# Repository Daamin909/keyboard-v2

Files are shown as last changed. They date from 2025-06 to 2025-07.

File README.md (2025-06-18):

# keyboard - v2

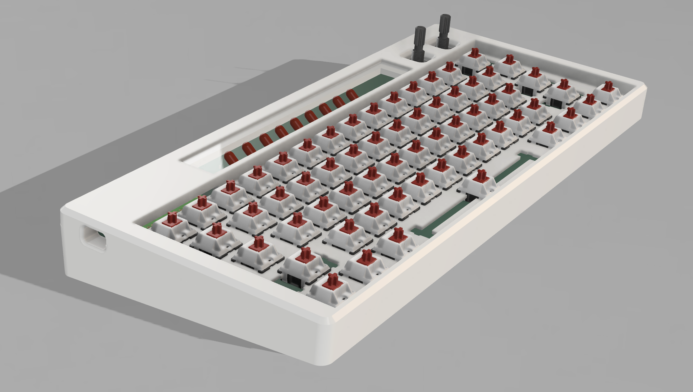
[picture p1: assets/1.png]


Made by [Daamin](https://daamin.tech)

Features:

- 61x keys!
- Default 60% Layout
- 2x EC11 Rotary Encoder - For Volume, Brightness etc
- 9x LEDs with acrylic for aesthetics (multicolor)
- COOOL Silkscreen
- 5° inclined case
- Comfy Design
- KMK firmware

## Info

I made this keyboard since I wanted a compact alternative to my bigger keyboard, this keyboard is pretty small in size and has most of the necessary keys. I also wanted to make this one look aesthetically pleasing instead of my old keyboard which did not look really good 😭.

It has 9x LEDs, out of which 3 are Red, Blue and Green. I did not use neopixels since PCBA is a bit expensive, and SMD soldering is out of my league for now.

In order to mount the acrylic sheet that is on top of the cutout, I designed a 3D printed part that will be super glued to hold it in place.

I will be using a cool green gradient keycaps, which will blend really well with the white case and the black PCB. The PCB will be visible from the LED cutout. The silkscreen also looks very good and is Harry Potter Themed.

## PCB

The PCB's size is 290.9mm x 123.4mm

| Schematic                 |
| ------------------------- |
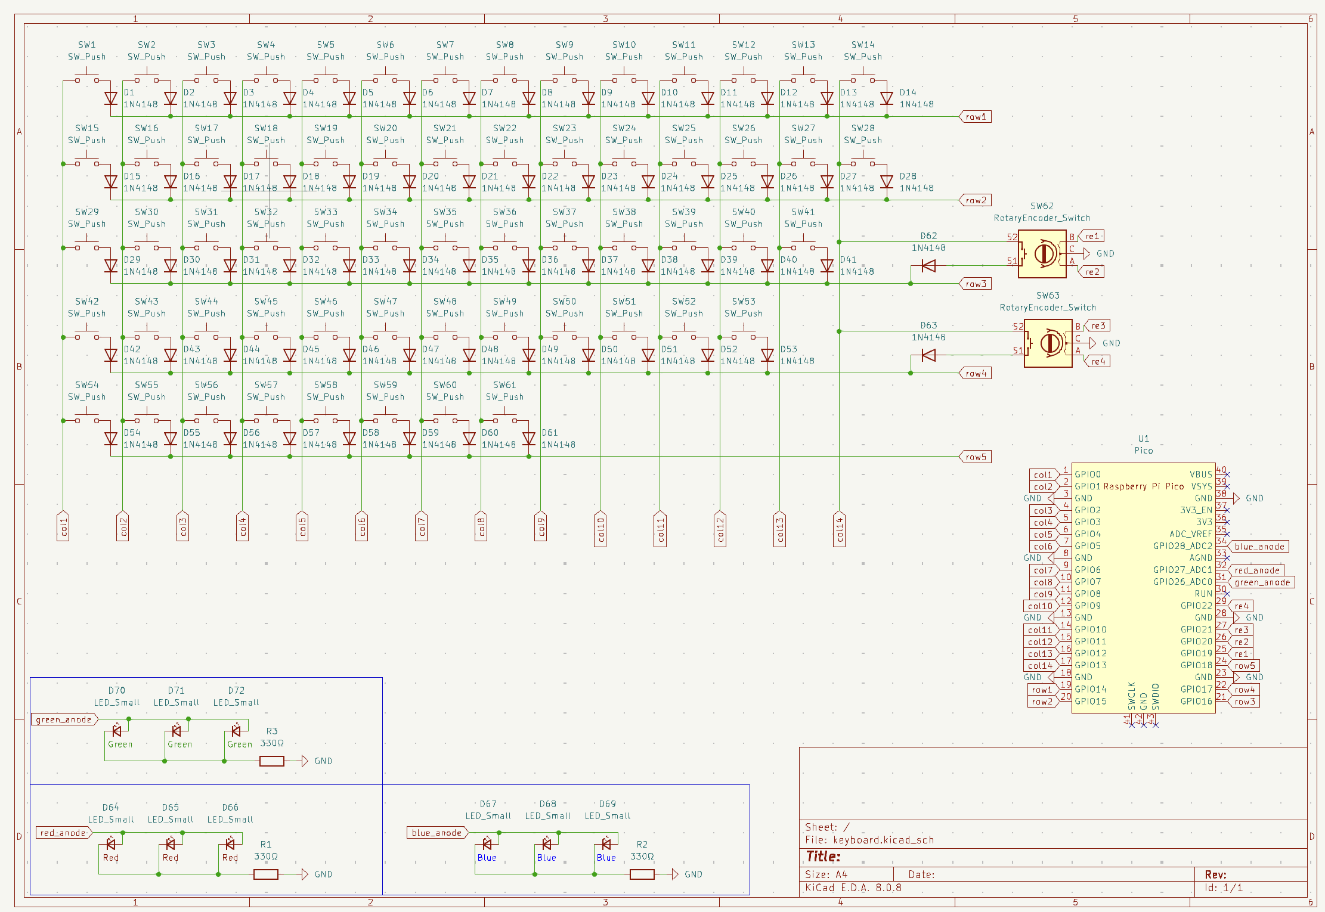
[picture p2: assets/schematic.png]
|  |

| Front                 |
| --------------------- |
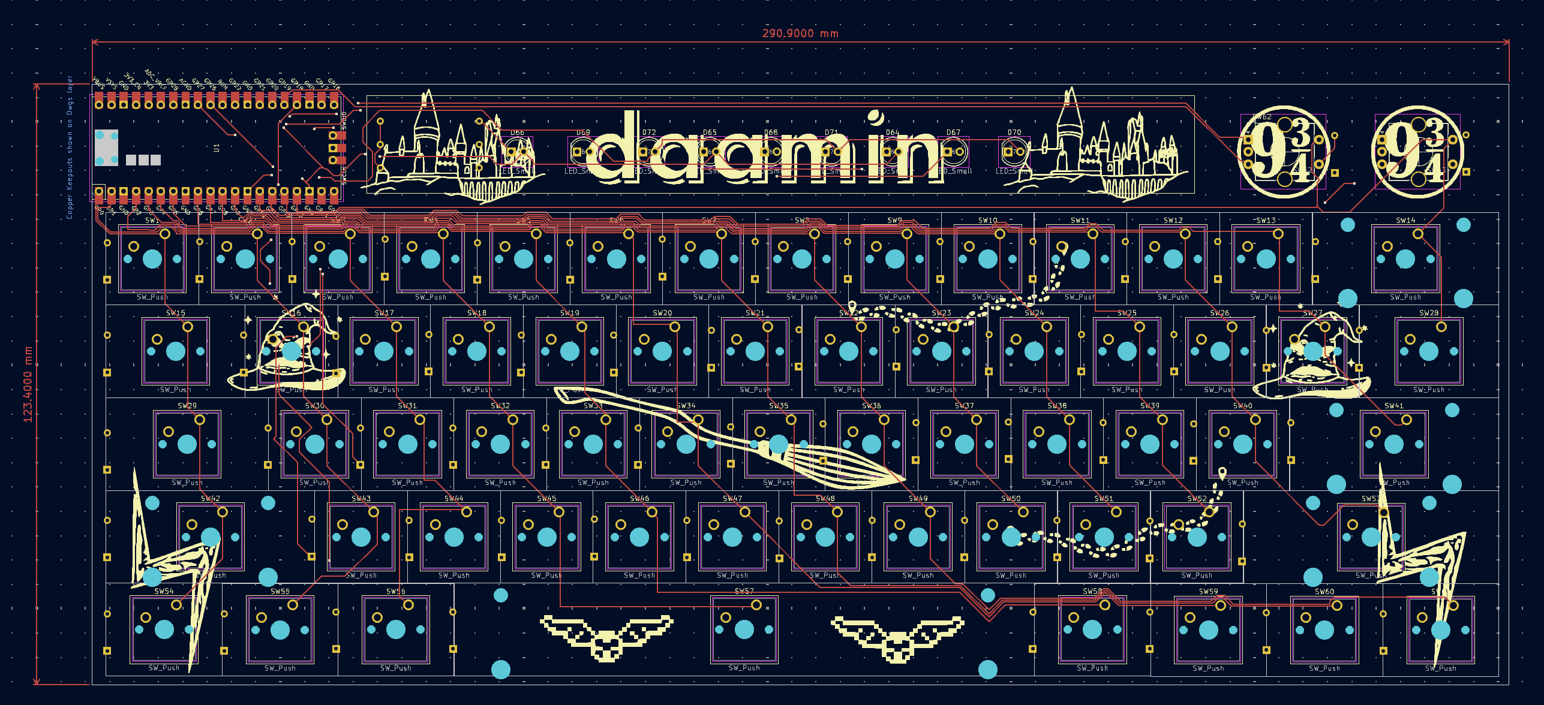
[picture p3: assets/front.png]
|  |

| Back                 |
| -------------------- |
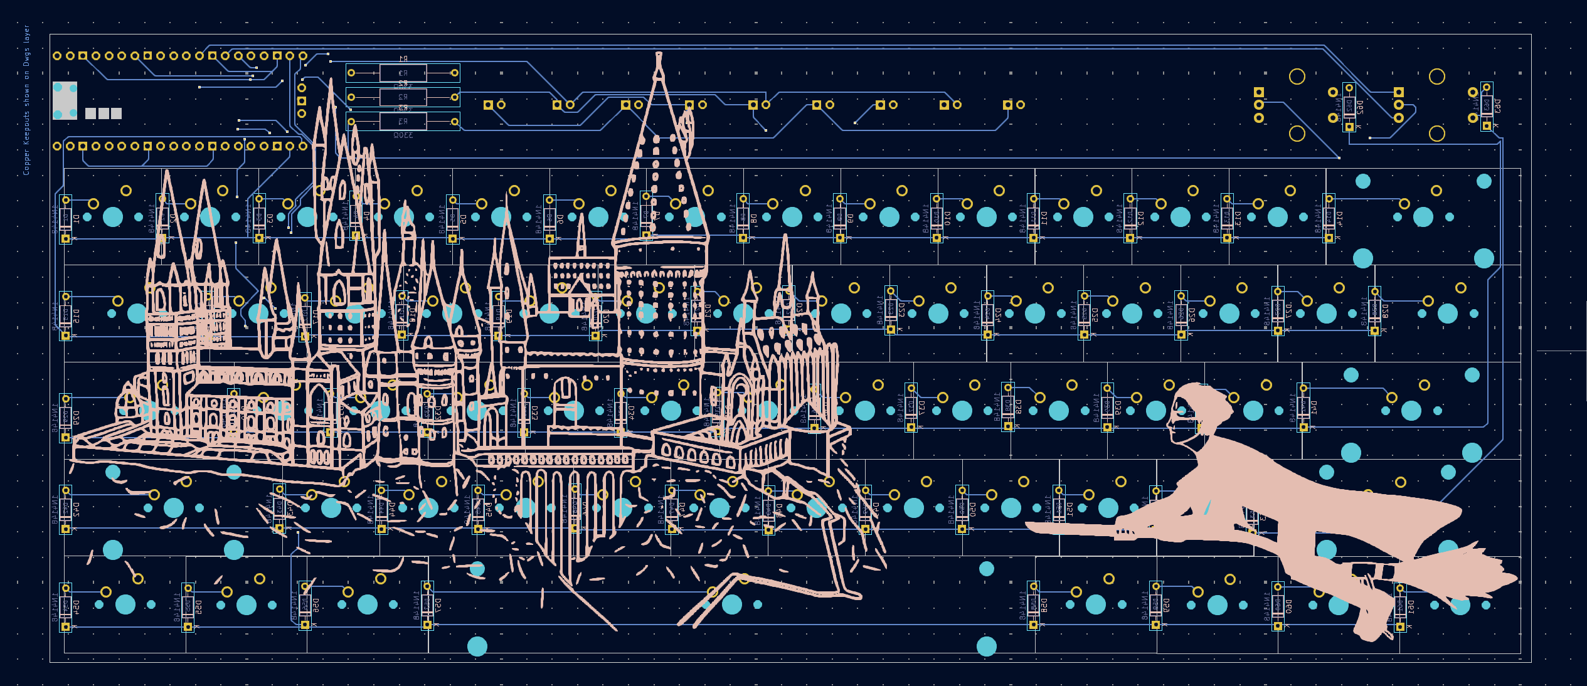
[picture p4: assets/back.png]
|  |

| 3D - Front               |
| ------------------------ |
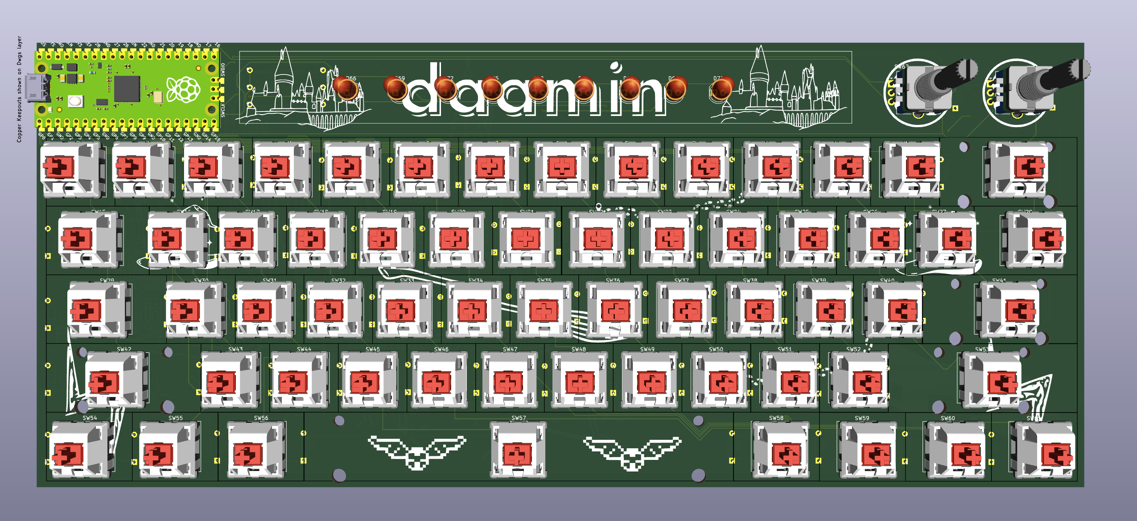
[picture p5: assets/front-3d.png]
|  |

| 3D - Back               |
| ----------------------- |
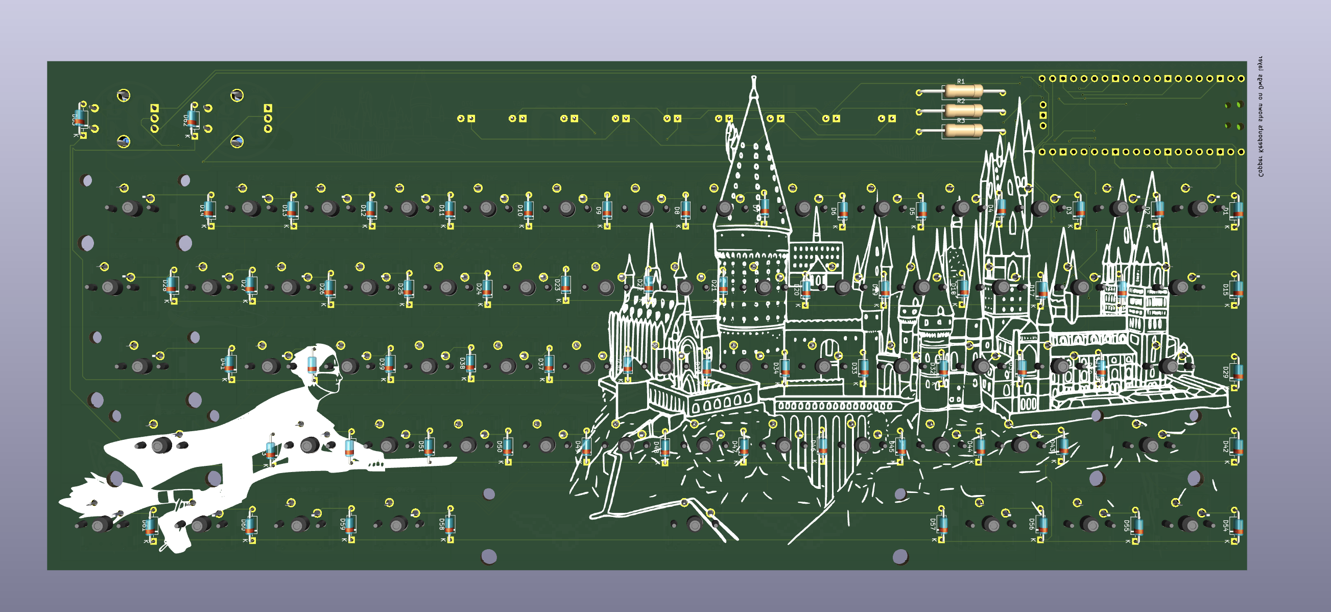
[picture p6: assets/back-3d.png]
|  |

## Case

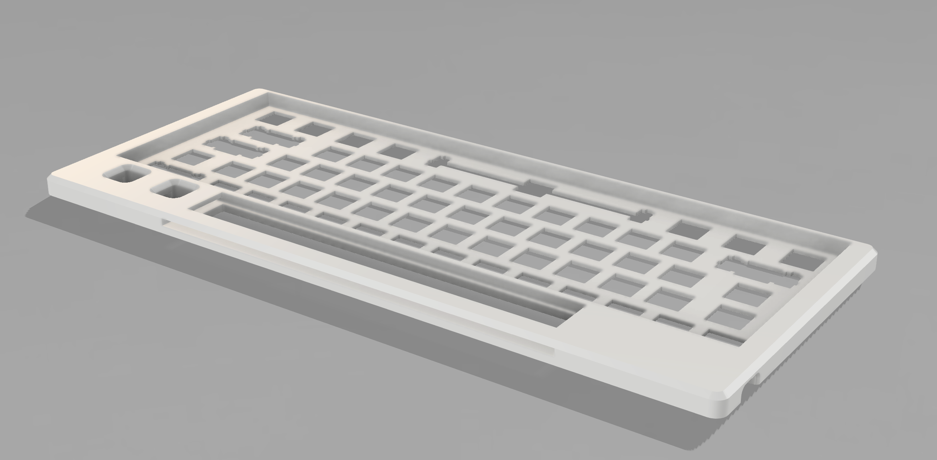
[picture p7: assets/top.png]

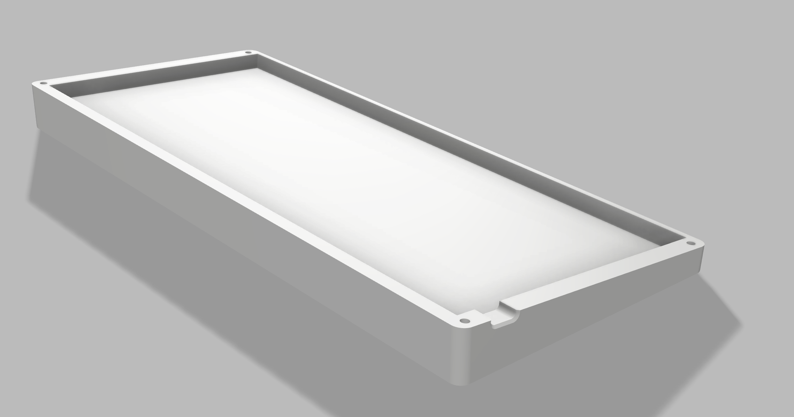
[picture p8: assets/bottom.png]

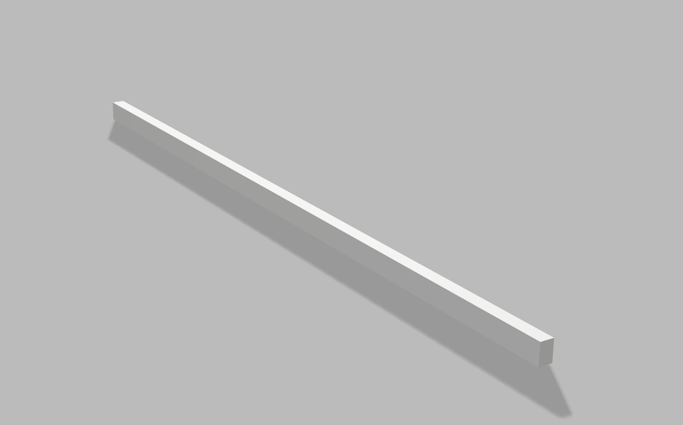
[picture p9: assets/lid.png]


The case was made in Fusion360.
The last image is of the 3D printed part to hold the acrylic sheet in place.
I chose to add branding on the bottom case only for aesthetics.

## 3D Render:


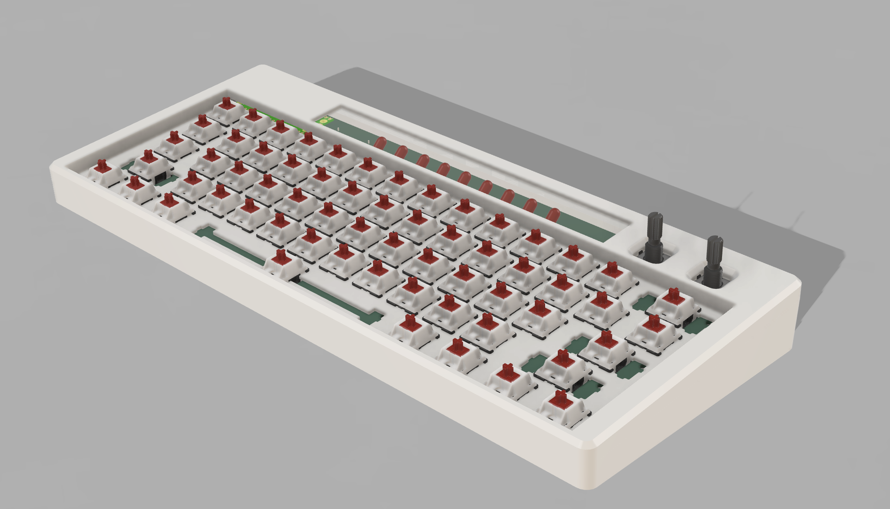
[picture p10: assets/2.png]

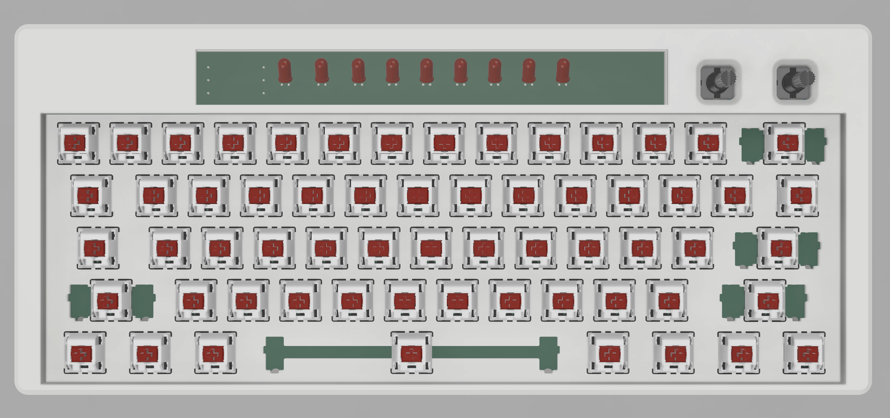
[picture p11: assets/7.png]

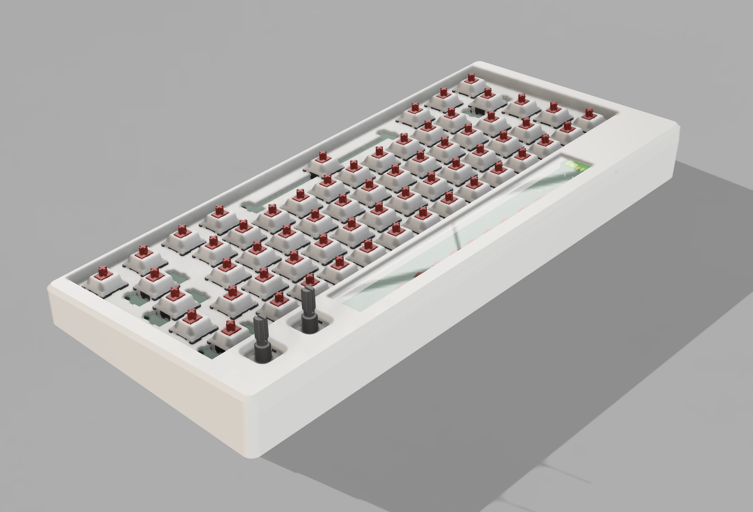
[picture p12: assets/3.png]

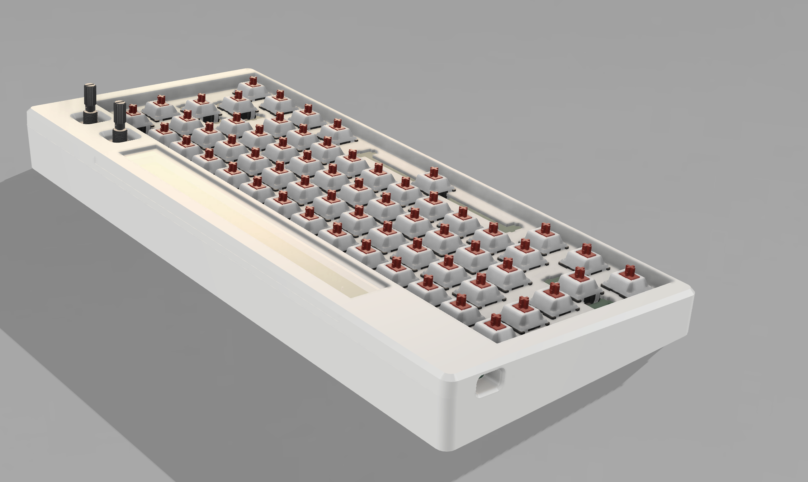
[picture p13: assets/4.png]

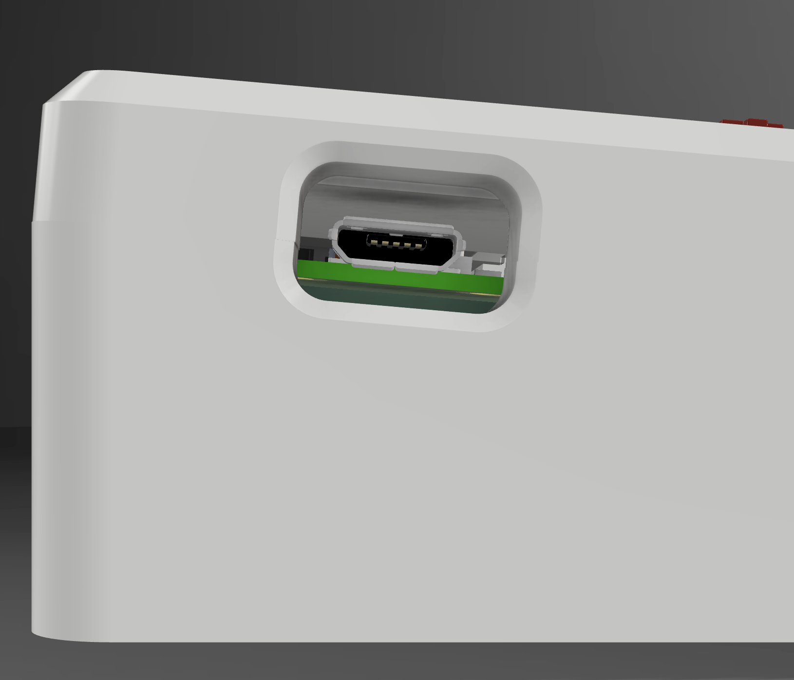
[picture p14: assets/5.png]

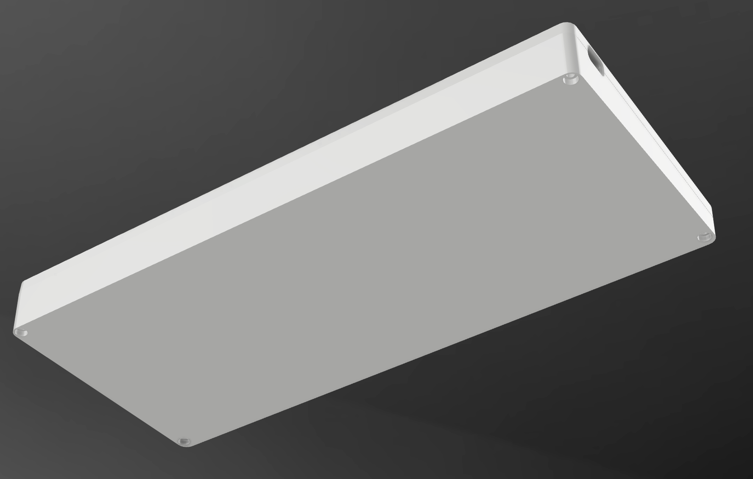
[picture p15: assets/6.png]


## Layout:

The Layout is a Default 60%.

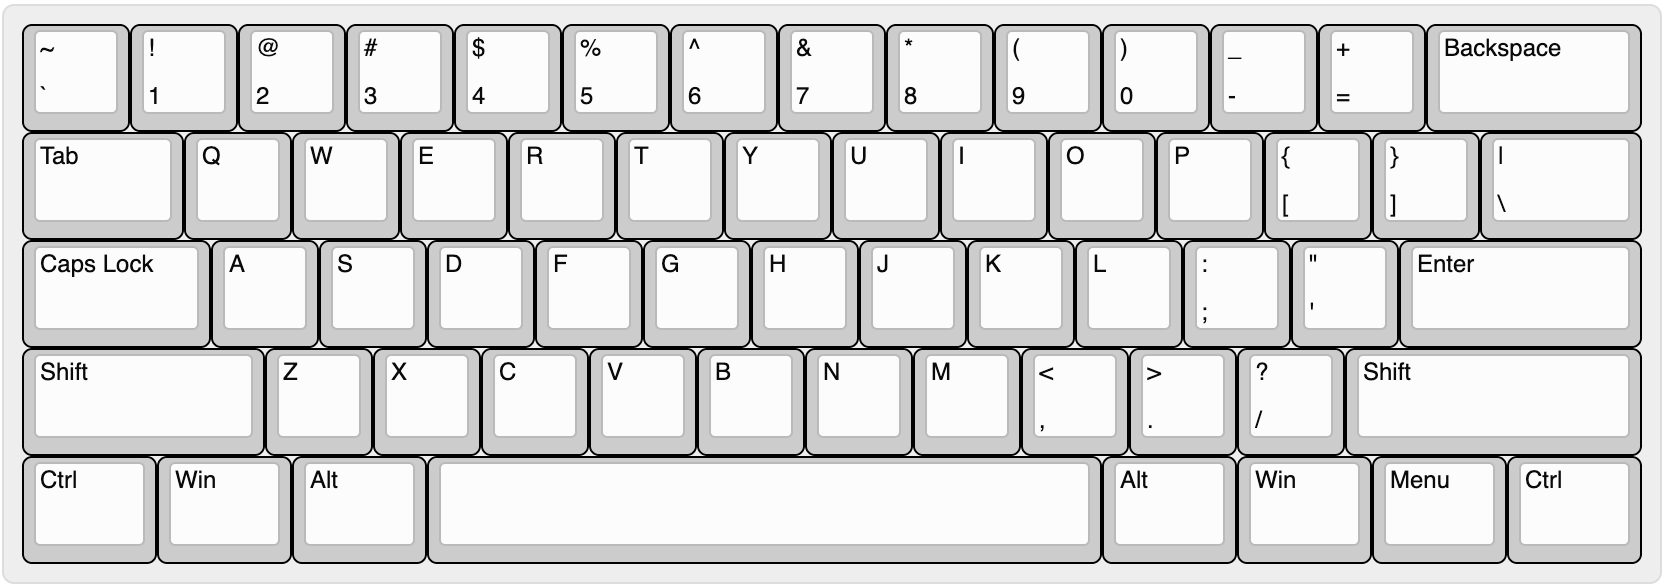
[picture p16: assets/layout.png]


## BOM

| Name | Qty | Final Price - INR (USD) | Link |
| --- | --- | --- | --- |
| Gateron EF Grayish | 70  | 1465 ($17.14) | [here](https://neomacro.in/products/gateron-ef-grayish) |
| Cherry Profile PBT Keycaps | 1 | 1299 ($15.14) | [here](https://stackskb.com/store/veekos-gradient-keycaps-cherry-profile-135-keys) |
| Durock Smokey Screw-In Stabilizers V2 (4+1 w/ 6.25u spacebar) | 1 | 1595 ($18.6) | [here](https://stackskb.com/store/durock-smokey-screw-in-stabilizers-v2/) |
| Diode 1N4148 Through - Hole | 80  | 188.8 ($2.21) | [here](https://roboticsdna.in/product/diode-1n4148/) |
| EC11 Rotary Encoder | 2 | 178 ($2.08) | [here](https://amzn.in/d/hVRxzij) |
| M3 x 16mm Bolt | 10  | 124 ($1.44) | [here](https://amzn.in/d/0eY6kT4) |
| M3 x 25mm Bolt | 10  | 145 ($1.69) | [here](https://amzn.in/d/3zS0SJ2) |
| M3 x 4mm Heatset Insert | 25  | 242 ($2.83) | [here](https://amzn.in/d/dpL3N2a) |
| PCB - (Black Color) | 5 | 3802.44 ($44.5) | [here](https://hc-cdn.hel1.your-objectstorage.com/s/v3/3f05c160f070155d4d5333c6b8261f5120b33c4c_image.png) |
| Raspberry Pi Pico | 1 | 366.01 ($4.28) | [here](https://roboticsdna.in/product/raspberry-pi-pico/) |
| Super Bright Red LED 5MM (5 Pieces) | 2 | 48 ($0.56) | [here](https://roboticsdna.in/product/super-bright-red-led-5mm-5-pieces/) |
| Super Bright Blue LED 5MM (5 Pieces) | 2 | 30 ($0.35) | [here](https://roboticsdna.in/product/super-bright-blue-led-5mm-5-pieces/) |
| Super Bright Green LED 5MM (5 Pieces) | 2 | 24 ($0.28) | [here](https://roboticsdna.in/product/super-bright-green-led-5mm-5-pieces/) |
| 330K Ohm 0.25W CFR Resistor ±5% Tolerance (Pack of 50 ) | 1 | 29.5 ($0.35) | [here](https://roboticsdna.in/product/330k-ohm-0-25w-cfr-resistor-%c2%b15-tolerance-pack-of-50/) |
| Acrylic Sheet | 1 | 240 ($2.81) | [here](https://amzn.in/d/05dUxqd) |
| Top Case - 1 (White "./production/top.step") | 1 | 2582 ($29.89) | [from 3ding.in](https://hc-cdn.hel1.your-objectstorage.com/s/v3/a1089c5d17e005a69043bc950fa28f1e25543591_image.png) |
| Rotary Encoder Knob | 2 | Print Legion |
| Bottom Case - 1 (White "./production/bottom.step") | 1 | Print Legion |
| Acrylic Sheet Mount - 1 (White "./production/acrylic-sheet-lid.step") | 1 | Print Legion |

## Total Pricing

The keyboard comes out to be approximately 12,300 INR ($142.38) when adding ordered parts and PCB. Does not include 3D - Printed case and Knob.
PS:- (Seed Studio costs $142 )
I have chose "air registered mail" over "UPS World Saver" because air registered mail is less likely to get customs even if it is more expensive.

## Notes :-

I want all the three 3D-printed parts to be printed in white color.

Some of the above items, were ordered in packs due to unavailability of singular items.
The pricing might slightly vary due to flash sales, and dollar market trends.

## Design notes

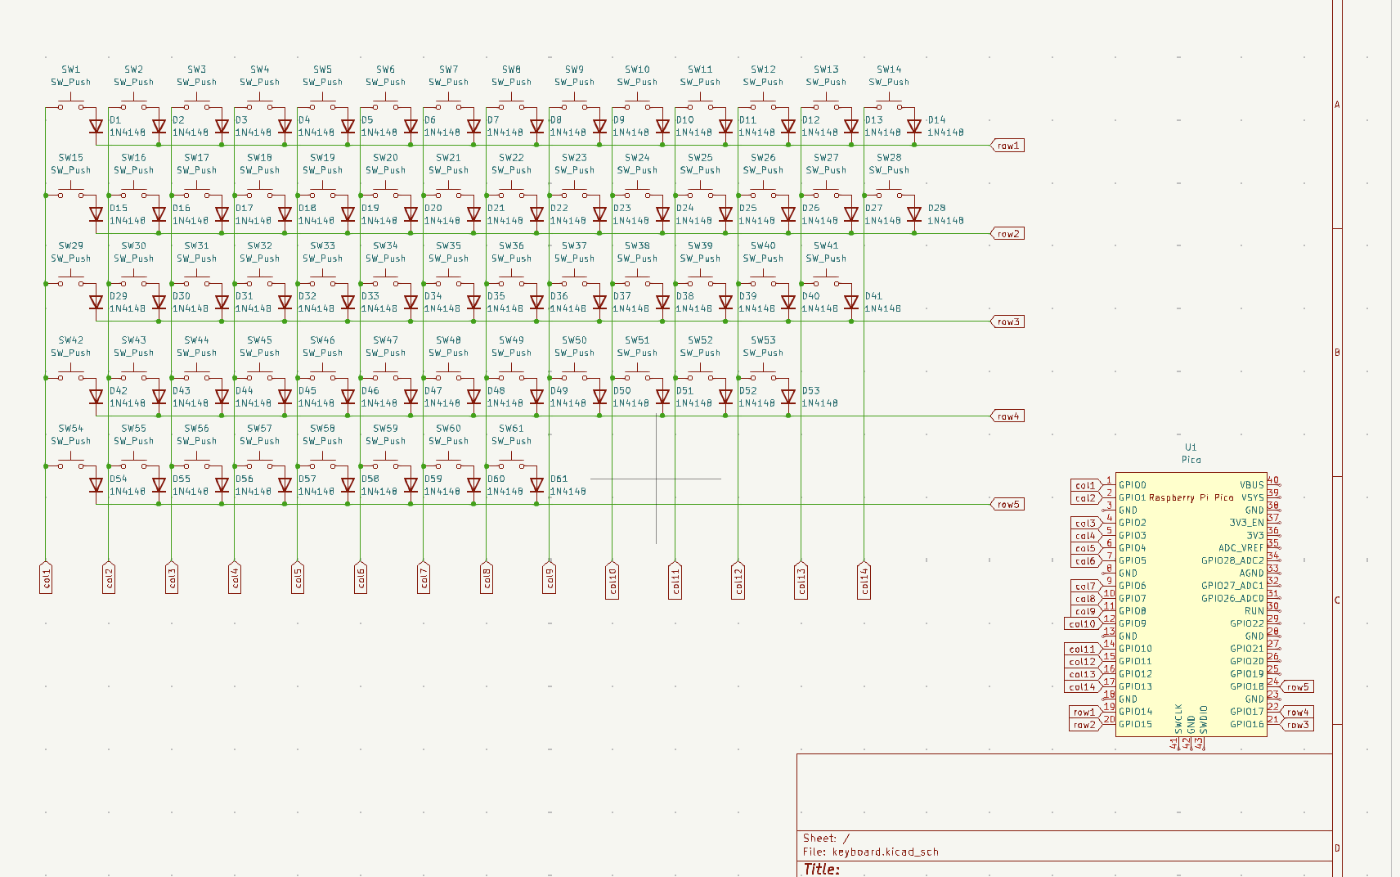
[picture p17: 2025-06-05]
assets/schem.png

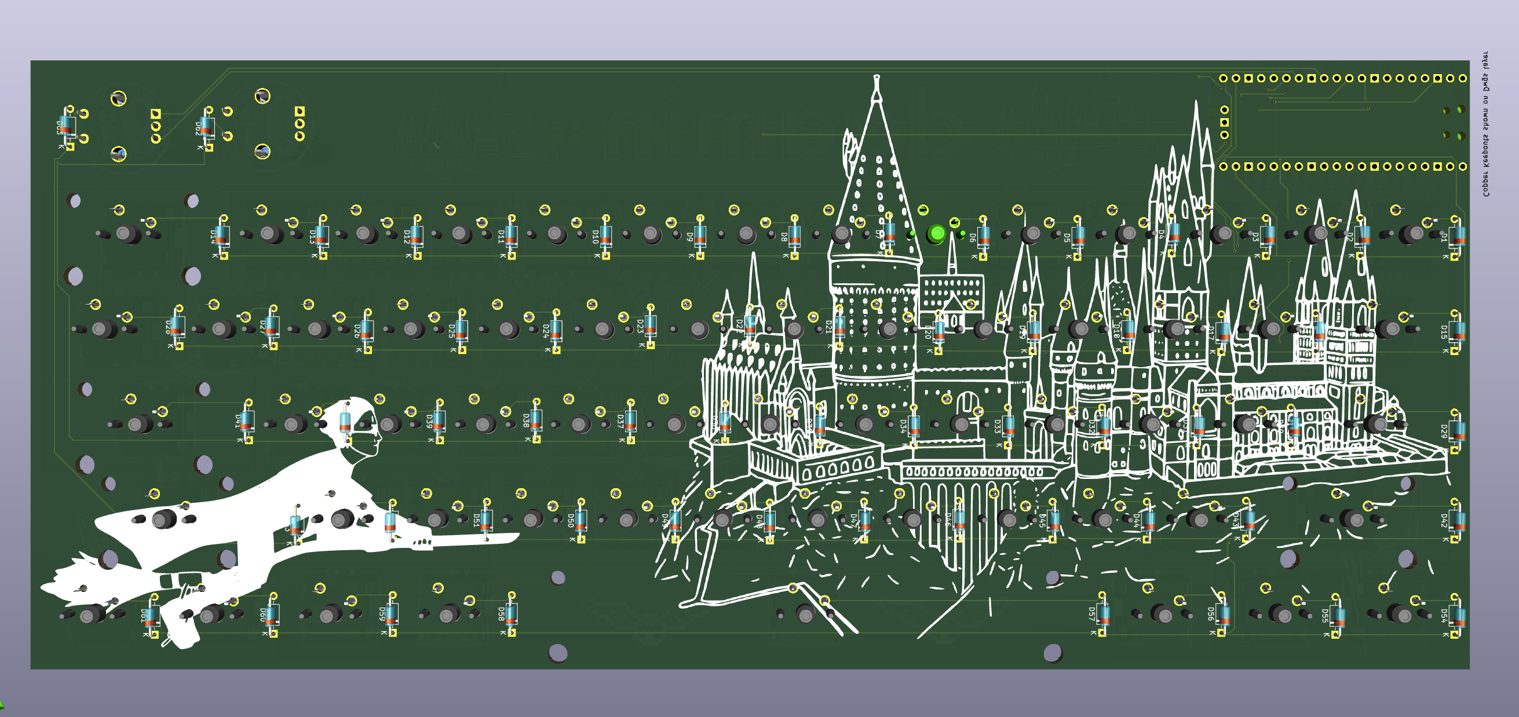
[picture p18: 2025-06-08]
assets/back_3d.png

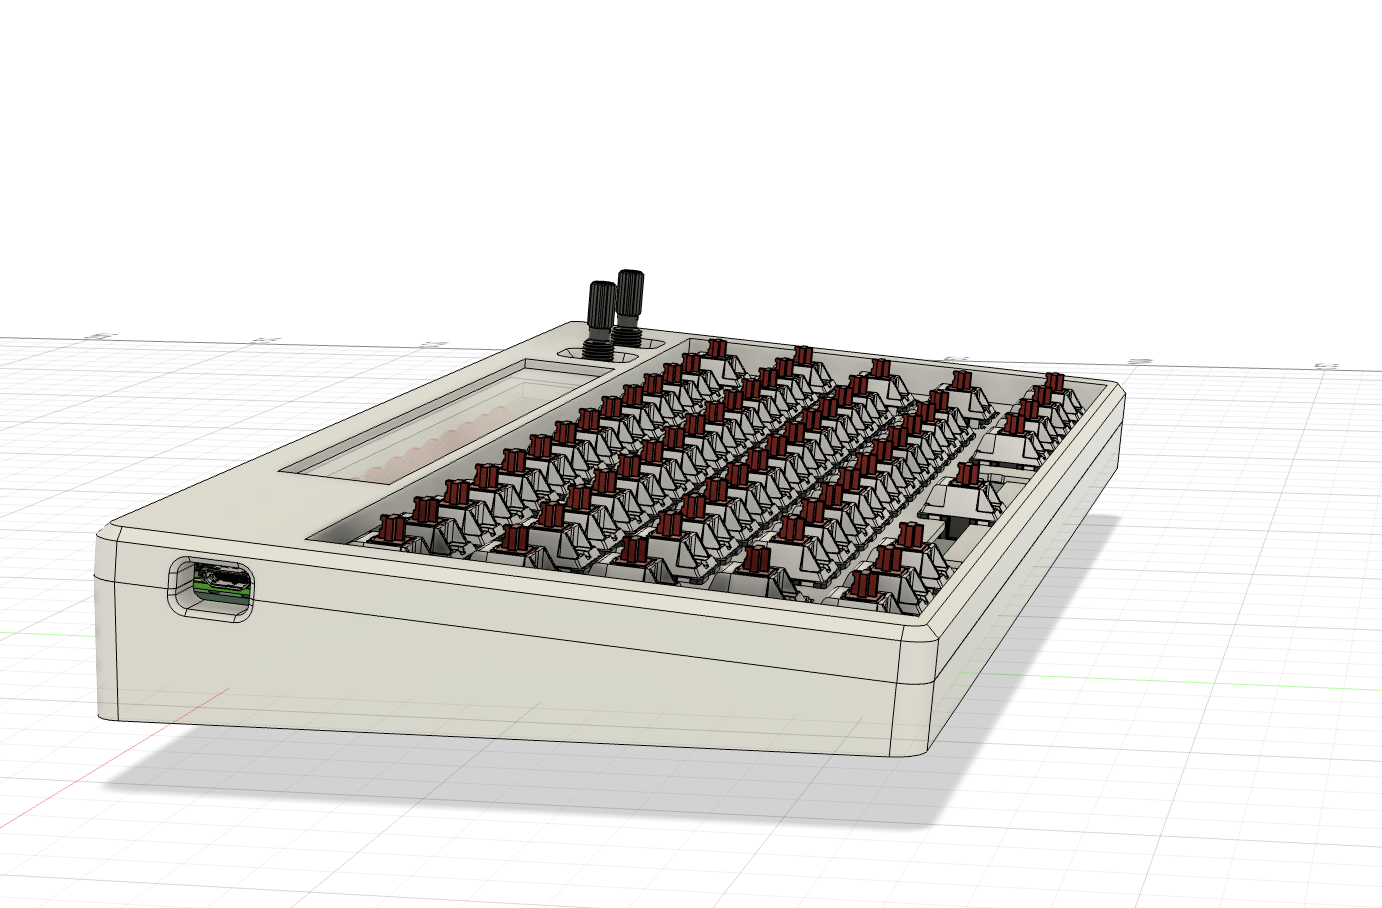
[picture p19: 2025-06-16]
assets/sus.png

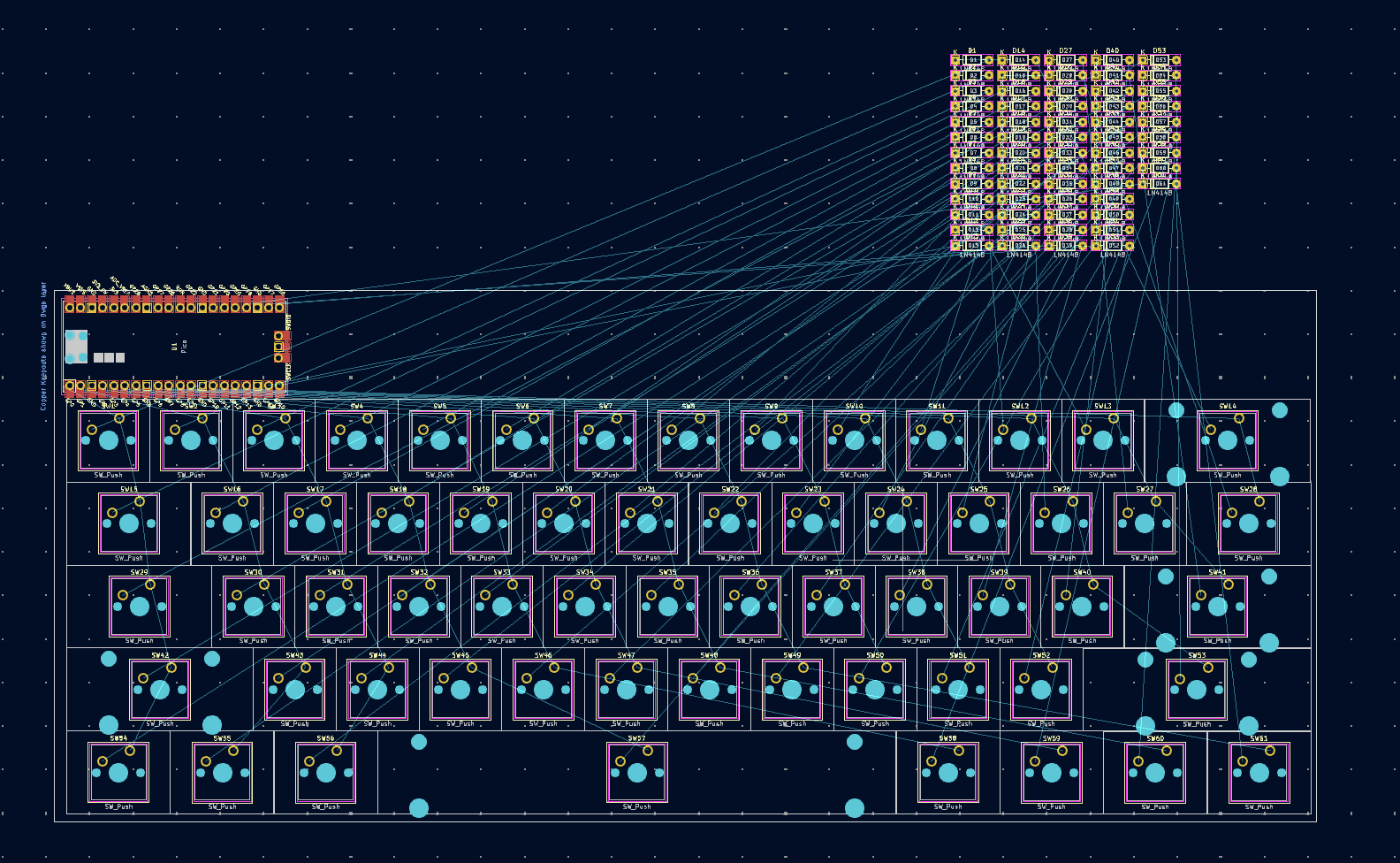
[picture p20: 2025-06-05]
assets/pcb.png

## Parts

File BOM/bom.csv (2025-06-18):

Name | Qty | Final Price - INR (USD) | Link
Gateron EF Grayish | 70 | 1465 ($17.14) | https://neomacro.in/products/gateron-ef-grayish
Cherry Profile PBT Keycaps | 1 | 1299 ($15.14) | https://stackskb.com/store/veekos-gradient-keycaps-cherry-profile-135-keys
Durock Smokey Screw-In Stabilizers V2 (4+1 w/ 6.25u spacebar) | 1 | 1595 ($18.6) | https://stackskb.com/store/durock-smokey-screw-in-stabilizers-v2/
Diode 1N4148 Through - Hole | 80 | 188.8 ($2.21) | https://roboticsdna.in/product/diode-1n4148/
EC11 Rotary Encoder | 2 | 178 ($2.08) | https://amzn.in/d/hVRxzij
M3 x 16mm Bolt | 10 | 124 ($1.44) | https://amzn.in/d/0eY6kT4
M3 x 25mm Bolt | 10 | 145 ($1.69) | https://amzn.in/d/3zS0SJ2
M3 x 4mm Heatset Insert | 25 | 242 ($2.83) | https://amzn.in/d/dpL3N2a
PCB - (Black Color) | 5 | 3802.44 ($44.5) | https://hc-cdn.hel1.your-objectstorage.com/s/v3/3f05c160f070155d4d5333c6b8261f5120b33c4c_image.png
Raspberry Pi Pico | 1 | 366.01 ($4.28) | https://roboticsdna.in/product/raspberry-pi-pico/
Super Bright Red LED 5MM (5 Pieces) | 2 | 48 ($0.56) | https://roboticsdna.in/product/super-bright-red-led-5mm-5-pieces/
Super Bright Blue LED 5MM (5 Pieces) | 2 | 30 ($0.35) | https://roboticsdna.in/product/super-bright-blue-led-5mm-5-pieces/
Super Bright Green LED 5MM (5 Pieces) | 2 | 24 ($0.28) | https://roboticsdna.in/product/super-bright-green-led-5mm-5-pieces/
330K Ohm 0.25W CFR Resistor ±5% Tolerance (Pack of 50 ) | 1 | 29.5 ($0.35) | https://roboticsdna.in/product/330k-ohm-0-25w-cfr-resistor-%c2%b15-tolerance-pack-of-50/
Acrylic Sheet | 1 | 240 ($2.81) | https://amzn.in/d/05dUxqd
Top Case - 1 (White "./production/top.step") | 1 | 2582 ($29.89) | https://hc-cdn.hel1.your-objectstorage.com/s/v3/a1089c5d17e005a69043bc950fa28f1e25543591_image.png
Rotary Encoder Knob | 2 | Print Legion
Bottom Case - 1 (White "./production/bottom.step") | 1 | Print Legion
Acrylic Sheet Mount - 1 (White "./production/acrylic-sheet-lid.step") | 1 | Print Legion

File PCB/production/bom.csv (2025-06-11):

Designator | Footprint | Quantity | Value | LCSC Part #
D1, D10, D11, D12, D13, D14, D15, D16, D17, D18, D19, D2, D20, D21, D22, D23, D24, D25, D26, D27, D28, D29, D3, D30, D31, D32, D33, D34, D35, D36, D37, D38, D39, D4, D40, D41, D42, D43, D44, D45, D46, D47, D48, D49, D5, D50, D51, D52, D53, D54, D55, D56, D57, D58, D59, D6, D60, D61, D62, D63, D7, D8, D9 | D_DO-35_SOD27_P7.62mm_Horizontal | 63 | 1N4148
D64, D65, D66, D67, D68, D69, D70, D71, D72 | LED_D5.0mm | 9 | LED_Small
R1, R2, R3 | R_Axial_DIN0309_L9.0mm_D3.2mm_P20.32mm_Horizontal | 3 | 330Ω
SW1, SW10, SW11, SW12, SW13, SW16, SW17, SW18, SW19, SW2, SW20, SW21, SW22, SW23, SW24, SW25, SW26, SW27, SW3, SW30, SW31, SW32, SW33, SW34, SW35, SW36, SW37, SW38, SW39, SW4, SW40, SW43, SW44, SW45, SW46, SW47, SW48, SW49, SW5, SW50, SW51, SW52, SW6, SW7, SW8, SW9 | SW_Cherry_MX_1.00u_PCB | 46 | SW_Push
SW14 | SW_Cherry_MX_2.00u_PCB | 1 | SW_Push
SW15, SW28 | SW_Cherry_MX_1.50u_PCB | 2 | SW_Push
SW29 | SW_Cherry_MX_1.75u_PCB | 1 | SW_Push
SW41, SW42 | SW_Cherry_MX_2.25u_PCB | 2 | SW_Push
SW53 | SW_Cherry_MX_2.75u_PCB | 1 | SW_Push
SW54, SW55, SW56, SW58, SW59, SW60, SW61 | SW_Cherry_MX_1.25u_PCB | 7 | SW_Push
SW57 | SW_Cherry_MX_6.25u_PCB | 1 | SW_Push
SW62, SW63 | RotaryEncoder_Alps_EC11E-Switch_Vertical_H20mm_CircularMountingHoles | 2 | RotaryEncoder_Switch
U1 | RPi_Pico_SMD_TH | 1 | Pico

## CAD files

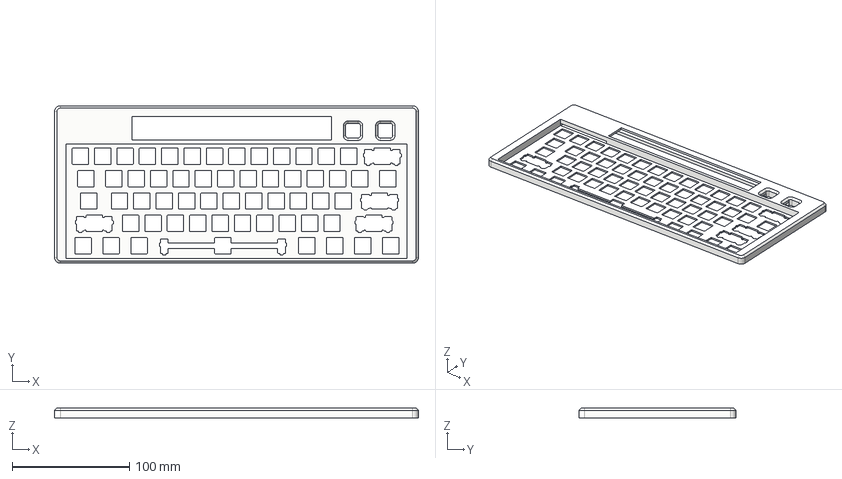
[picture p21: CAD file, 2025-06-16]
CAD/top.step
310.0 x 134.0 x 8.50 mm

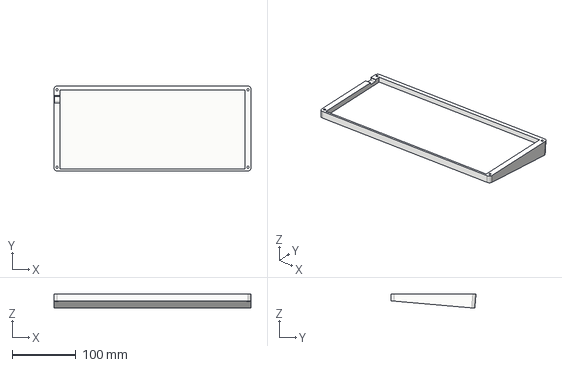
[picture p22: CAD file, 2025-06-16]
CAD/bottom.step
310.0 x 134.0 x 22.6 mm

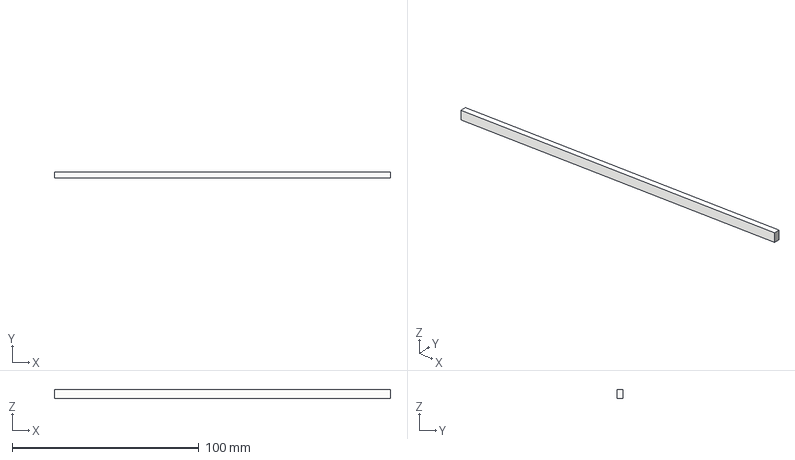
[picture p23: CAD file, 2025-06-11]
CAD/acrylic-sheet-lid.step
180.0 x 3.20 x 5.00 mm

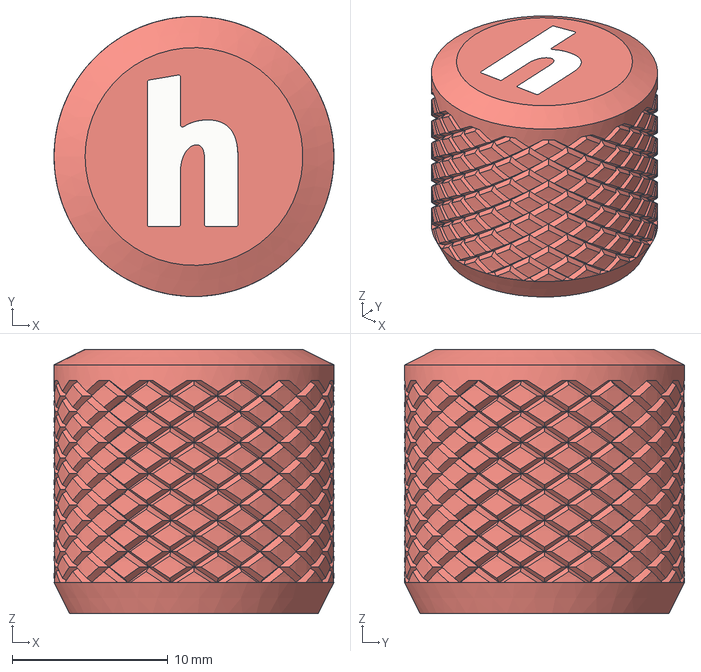
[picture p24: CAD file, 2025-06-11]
production/knurled_knob.step
18.0 x 18.0 x 17.0 mm
Base
H

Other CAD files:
CAD/stl/acrylic-sheet-lid.stl
CAD/stl/bottom.stl
CAD/stl/top.stl

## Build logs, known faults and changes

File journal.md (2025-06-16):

---
title: "keyboard-v2"
author: "Daamin Ashai"
description: "a smart & cool keyboard"
created_at: "2025-06-05"
---

**Total Time Spent: 18 hours**

# keyboard-v2 - a custom keyboard

### 5th June (day 1): brainstorming & schematic

oooo this is gonna be hella fun.
i've already designed a keyboard before this but that one was a bit chunky, with this keyboard, I plan to make it very minimalistic and compact, so it becomes very portable. I also want to print the case in one piece using my own 3D printer which i'm working on right now, it has a build plate of 310mm x 310mm. Meaning I want my keeb to slightly smaller than that. I ended up choosing a 60% layout. I also want to use slide potentiometers and REs for this keyboard.

I designed the layout using kb-layout-editor, and finished the schematic for the switches. I also worked on the aligning the switches.

<image src="assets/pcb.png" width="400">

<image src="assets/schem.png" width="400">

**Time Spent:** 2 hours

### 6th June (day 2): finish pcb

after some brainstorming, i decided to not use sliders since they're pretty unfit for what i do. i ended up adding 2 REs and some noepixels on the pcb. since the mcu takes space on the top, ill put some neopixels which will have a glass/acrylic top for aesthetics. i made a VERY cool harry potter themed silkscreen and im very happy with how it turned out. routing this time way way better than my prev keyboard and i actually used a lot less vias. ill work on the case next

<image src="assets/front_3d.png" width="400">

<image src="assets/back_3d.png" width="400">

**Time Spent**: 4 hours

### 7th June (day 3): make changes to save money

i removed the neopixels since i could not source them with in India, and PCBA would probably incur a lot of customs. I switched to using a bunch of LEDs. the colors will still look cool, and id save some money on customs.

<image src="assets/new.png" width="400">

**Time Spent**: 1 hour

### 10th June (day 4): finish CAD and complete the keyboard!!

I started working on the CAD, this time it was very easy, compared to last time when I was making a keyboard 😭.
I decided on making a integrated top and plate to make it quick to print. I used the plate generator and this time it was smoother than last time. it took me a while to figure out the fastener situation, but i ended up using heatsets and kept it very hidden. I decided to go with an all - white case, and found an acrylic sheet to cover the LEDs, i also made a way to mount this sheet using some superglue. it was very fun to make this, and the renders look AWESOME.

<image src="assets/1.png" width="400">
<image src="assets/2.png" width="400">
<image src="assets/3.png" width="400">
<image src="assets/4.png" width="400">
<image src="assets/5.png" width="400">
<image src="assets/6.png" width="400">

**Time Spent**: 6 hours

### 12th June (day 5): add firmware

i did some gpt-ing since its very hard to make the firmware without having the parts with me 😭. and BOOM I had a firmware, I made a tiny little function to cycle through my LED configs and thats it!

**Time Spent:** 1 hour

### 16th June (day 6): made the case inclined

i had some second thoughts on whether I should make my case inclined or not, and here we go. after some googling, i went with a 5 degree incline, and did some magic and once again BOOM. I added the holes for the fasteners and I was done! im really proud of how this ended up looking.

<image src="assets/sus.png" width="400">

**Time Spent**: 2 hours

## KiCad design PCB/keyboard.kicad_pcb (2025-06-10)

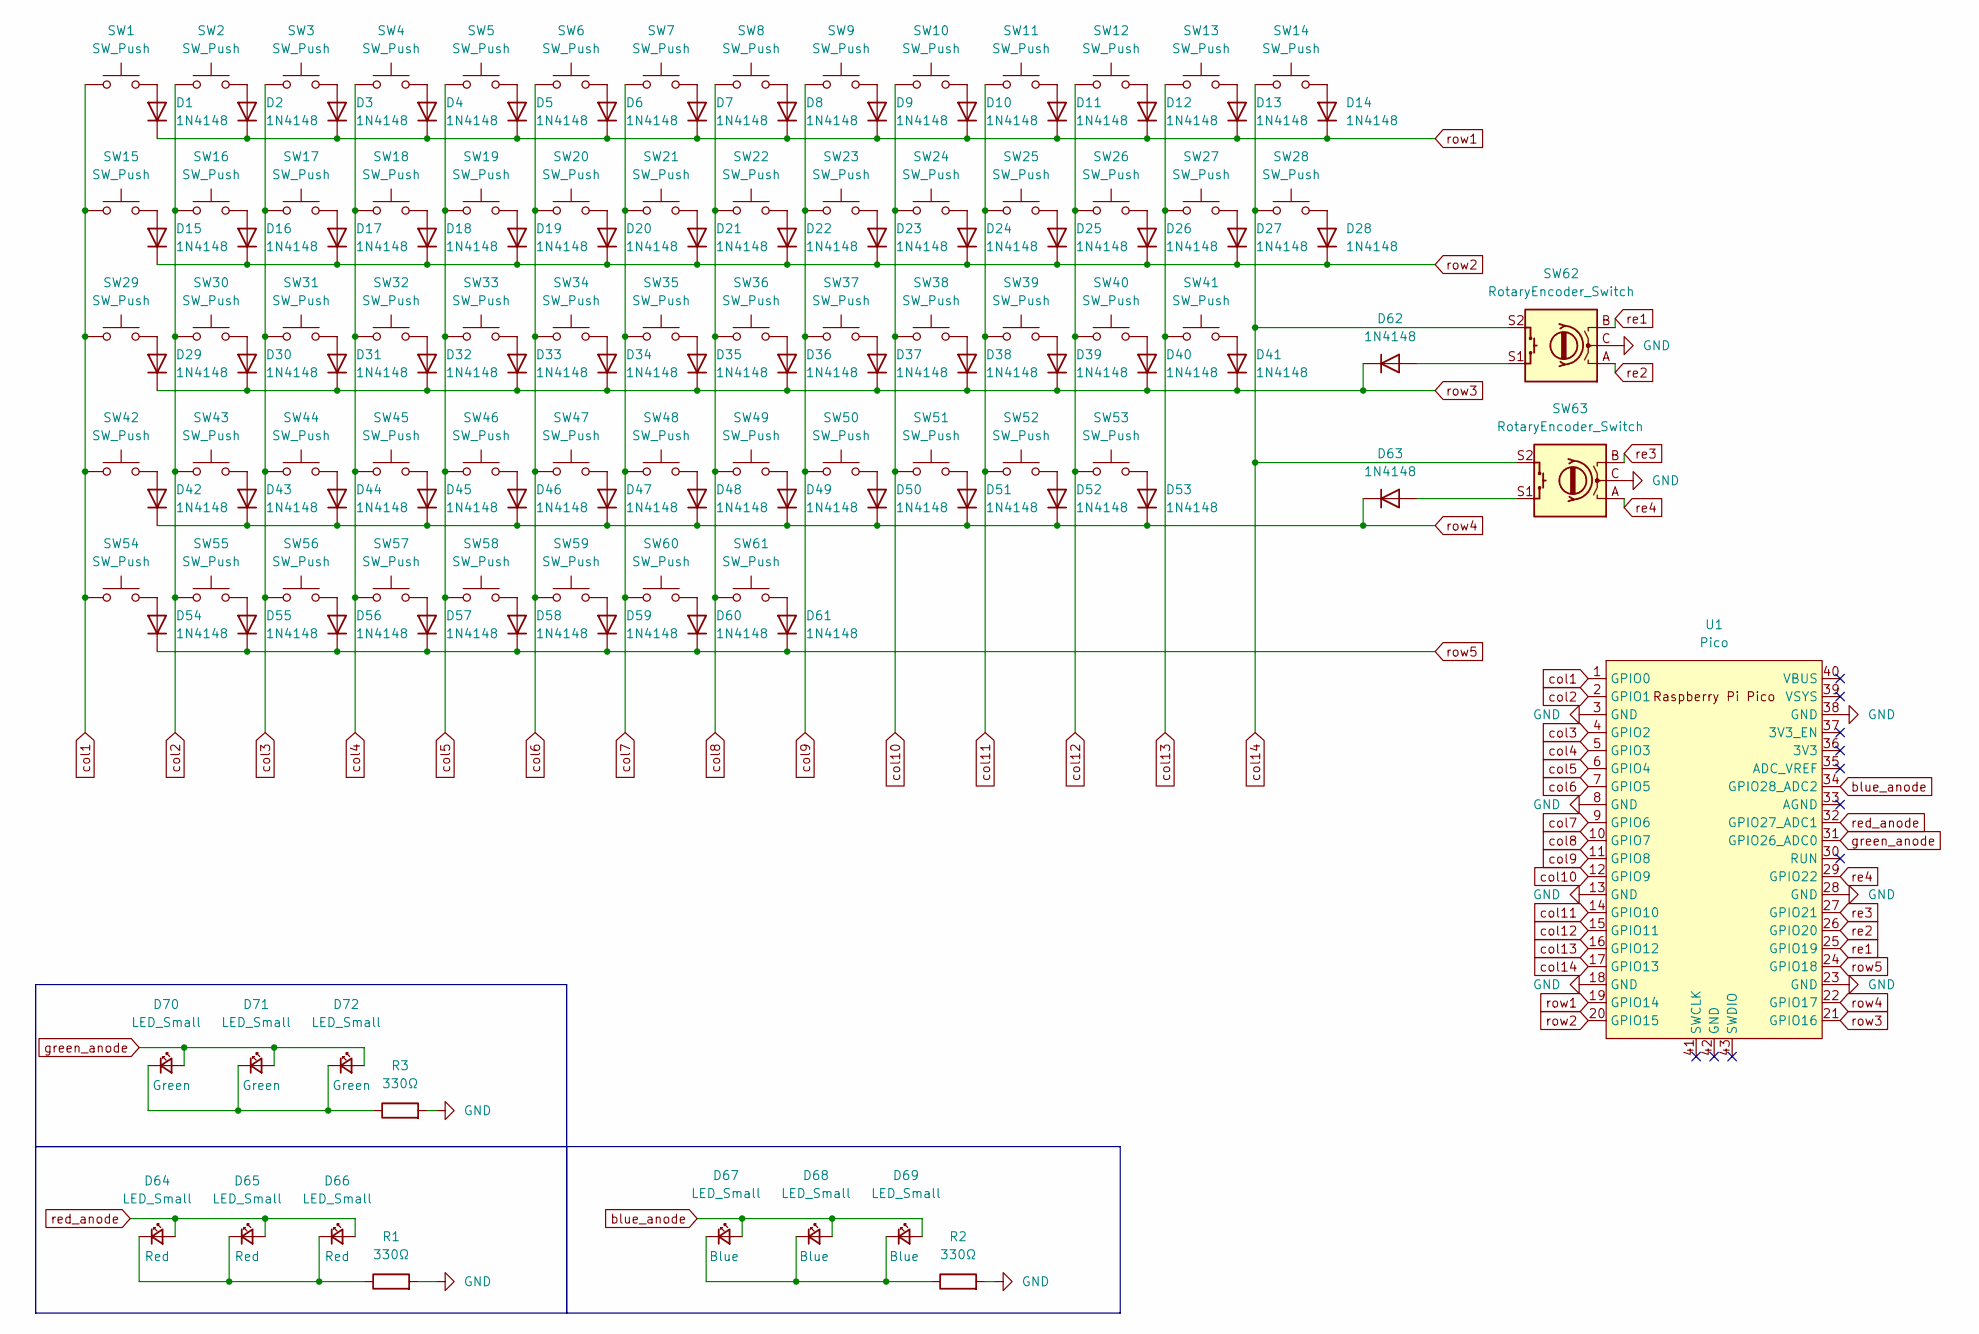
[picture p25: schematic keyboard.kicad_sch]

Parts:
D1, D2, D3, D4, D5, D6, D7, D8, D9, D10, D11, D12, D13, D14, D15, D16, D17, D18, D19, D20, D21, D22, D23, D24, D25, D26, D27, D28, D29, D30, D31, D32, D33, D34, D35, D36, D37, D38, D39, D40, D41, D42, D43, D44, D45, D46, D47, D48, D49, D50, D51, D52, D53, D54, D55, D56, D57, D58, D59, D60, D61, D62, D63: 1N4148; D_DO-35_SOD27_P7.62mm_Horizontal
D64, D65, D66, D67, D68, D69, D70, D71, D72: LED_Small; LED_D5.0mm
R1, R2, R3: 330Ω; R_Axial_DIN0309_L9.0mm_D3.2mm_P20.32mm_Horizontal
SW1, SW2, SW3, SW4, SW5, SW6, SW7, SW8, SW9, SW10, SW11, SW12, SW13, SW16, SW17, SW18, SW19, SW20, SW21, SW22, SW23, SW24, SW25, SW26, SW27, SW30, SW31, SW32, SW33, SW34, SW35, SW36, SW37, SW38, SW39, SW40, SW43, SW44, SW45, SW46, SW47, SW48, SW49, SW50, SW51, SW52: SW_Push; SW_Cherry_MX_1.00u_PCB
SW14: SW_Push; SW_Cherry_MX_2.00u_PCB
SW15, SW28: SW_Push; SW_Cherry_MX_1.50u_PCB
SW29: SW_Push; SW_Cherry_MX_1.75u_PCB
SW41, SW42: SW_Push; SW_Cherry_MX_2.25u_PCB
SW53: SW_Push; SW_Cherry_MX_2.75u_PCB
SW54, SW55, SW56, SW58, SW59, SW60, SW61: SW_Push; SW_Cherry_MX_1.25u_PCB
SW57: SW_Push; SW_Cherry_MX_6.25u_PCB
SW62, SW63: RotaryEncoder_Switch; RotaryEncoder_Alps_EC11E-Switch_Vertical_H20mm_CircularMoun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
U1: Pico; RPi_Pico_SMD_TH

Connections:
GND: R1.2, R2.2, R3.2, SW62.C, SW63.C, U1.3 (GND), U1.8 (GND), U1.13 (GND), U1.18 (GND), U1.23 (GND), U1.28 (GND), U1.38 (GND)
unnamed: D1.2 (A), SW1.2
unnamed: D2.2 (A), SW2.2
unnamed: D3.2 (A), SW3.2
unnamed: D4.2 (A), SW4.2
unnamed: D5.2 (A), SW5.2
unnamed: D6.2 (A), SW6.2
unnamed: D7.2 (A), SW7.2
unnamed: D8.2 (A), SW8.2
unnamed: D9.2 (A), SW9.2
unnamed: D10.2 (A), SW10.2
unnamed: D11.2 (A), SW11.2
unnamed: D12.2 (A), SW12.2
unnamed: D13.2 (A), SW13.2
unnamed: D14.2 (A), SW14.2
unnamed: D15.2 (A), SW15.2
unnamed: D16.2 (A), SW16.2
unnamed: D17.2 (A), SW17.2
unnamed: D18.2 (A), SW18.2
unnamed: D19.2 (A), SW19.2
unnamed: D20.2 (A), SW20.2
unnamed: D21.2 (A), SW21.2
unnamed: D22.2 (A), SW22.2
unnamed: D23.2 (A), SW23.2
unnamed: D24.2 (A), SW24.2
unnamed: D25.2 (A), SW25.2
unnamed: D26.2 (A), SW26.2
unnamed: D27.2 (A), SW27.2
unnamed: D28.2 (A), SW28.2
unnamed: D29.2 (A), SW29.2
unnamed: D30.2 (A), SW30.2
unnamed: D31.2 (A), SW31.2
unnamed: D32.2 (A), SW32.2
unnamed: D33.2 (A), SW33.2
unnamed: D34.2 (A), SW34.2
unnamed: D35.2 (A), SW35.2
unnamed: D36.2 (A), SW36.2
unnamed: D37.2 (A), SW37.2
unnamed: D38.2 (A), SW38.2
unnamed: D39.2 (A), SW39.2
unnamed: D40.2 (A), SW40.2
unnamed: D41.2 (A), SW41.2
unnamed: D42.2 (A), SW42.2
unnamed: D43.2 (A), SW43.2
unnamed: D44.2 (A), SW44.2
unnamed: D45.2 (A), SW45.2
unnamed: D46.2 (A), SW46.2
unnamed: D47.2 (A), SW47.2
unnamed: D48.2 (A), SW48.2
unnamed: D49.2 (A), SW49.2
unnamed: D50.2 (A), SW50.2
unnamed: D51.2 (A), SW51.2
unnamed: D52.2 (A), SW52.2
unnamed: D53.2 (A), SW53.2
unnamed: D54.2 (A), SW54.2
unnamed: D55.2 (A), SW55.2
unnamed: D56.2 (A), SW56.2
unnamed: D57.2 (A), SW57.2
unnamed: D58.2 (A), SW58.2
unnamed: D59.2 (A), SW59.2
unnamed: D60.2 (A), SW60.2
unnamed: D61.2 (A), SW61.2
unnamed: D62.2 (A), SW62.S1
unnamed: D63.2 (A), SW63.S1
unnamed: D64.1 (K), D65.1 (K), D66.1 (K), R1.1
unnamed: D67.1 (K), D68.1 (K), D69.1 (K), R2.1
unnamed: D70.1 (K), D71.1 (K), D72.1 (K), R3.1
blue_anode: D67.2 (A), D68.2 (A), D69.2 (A), U1.34 (GPIO28_ADC2)
col1: SW1.1, SW15.1, SW29.1, SW42.1, SW54.1, U1.1 (GPIO0)
col2: SW2.1, SW16.1, SW30.1, SW43.1, SW55.1, U1.2 (GPIO1)
col3: SW3.1, SW17.1, SW31.1, SW44.1, SW56.1, U1.4 (GPIO2)
col4: SW4.1, SW18.1, SW32.1, SW45.1, SW57.1, U1.5 (GPIO3)
col5: SW5.1, SW19.1, SW33.1, SW46.1, SW58.1, U1.6 (GPIO4)
col6: SW6.1, SW20.1, SW34.1, SW47.1, SW59.1, U1.7 (GPIO5)
col7: SW7.1, SW21.1, SW35.1, SW48.1, SW60.1, U1.9 (GPIO6)
col8: SW8.1, SW22.1, SW36.1, SW49.1, SW61.1, U1.10 (GPIO7)
col9: SW9.1, SW23.1, SW37.1, SW50.1, U1.11 (GPIO8)
col10: SW10.1, SW24.1, SW38.1, SW51.1, U1.12 (GPIO9)
col11: SW11.1, SW25.1, SW39.1, SW52.1, U1.14 (GPIO10)
col12: SW12.1, SW26.1, SW40.1, SW53.1, U1.15 (GPIO11)
col13: SW13.1, SW27.1, SW41.1, U1.16 (GPIO12)
col14: SW14.1, SW28.1, SW62.S2, SW63.S2, U1.17 (GPIO13)
green_anode: D70.2 (A), D71.2 (A), D72.2 (A), U1.31 (GPIO26_ADC0)
re1: SW62.B, U1.25 (GPIO19)
re2: SW62.A, U1.26 (GPIO20)
re3: SW63.B, U1.27 (GPIO21)
re4: SW63.A, U1.29 (GPIO22)
red_anode: D64.2 (A), D65.2 (A), D66.2 (A), U1.32 (GPIO27_ADC1)
row1: D1.1 (K), D2.1 (K), D3.1 (K), D4.1 (K), D5.1 (K), D6.1 (K), D7.1 (K), D8.1 (K), D9.1 (K), D10.1 (K), D11.1 (K), D12.1 (K), D13.1 (K), D14.1 (K), U1.19 (GPIO14)
row2: D15.1 (K), D16.1 (K), D17.1 (K), D18.1 (K), D19.1 (K), D20.1 (K), D21.1 (K), D22.1 (K), D23.1 (K), D24.1 (K), D25.1 (K), D26.1 (K), D27.1 (K), D28.1 (K), U1.20 (GPIO15)
row3: D29.1 (K), D30.1 (K), D31.1 (K), D32.1 (K), D33.1 (K), D34.1 (K), D35.1 (K), D36.1 (K), D37.1 (K), D38.1 (K), D39.1 (K), D40.1 (K), D41.1 (K), D62.1 (K), U1.21 (GPIO16)
row4: D42.1 (K), D43.1 (K), D44.1 (K), D45.1 (K), D46.1 (K), D47.1 (K), D48.1 (K), D49.1 (K), D50.1 (K), D51.1 (K), D52.1 (K), D53.1 (K), D63.1 (K), U1.22 (GPIO17)
row5: D54.1 (K), D55.1 (K), D56.1 (K), D57.1 (K), D58.1 (K), D59.1 (K), D60.1 (K), D61.1 (K), U1.24 (GPIO18)

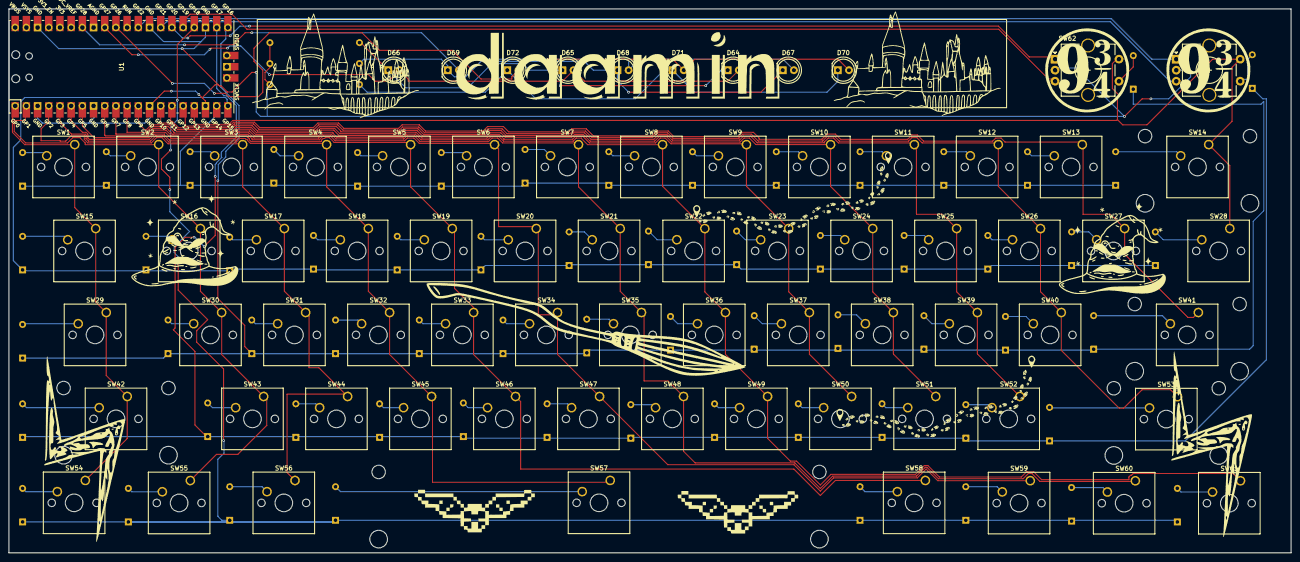
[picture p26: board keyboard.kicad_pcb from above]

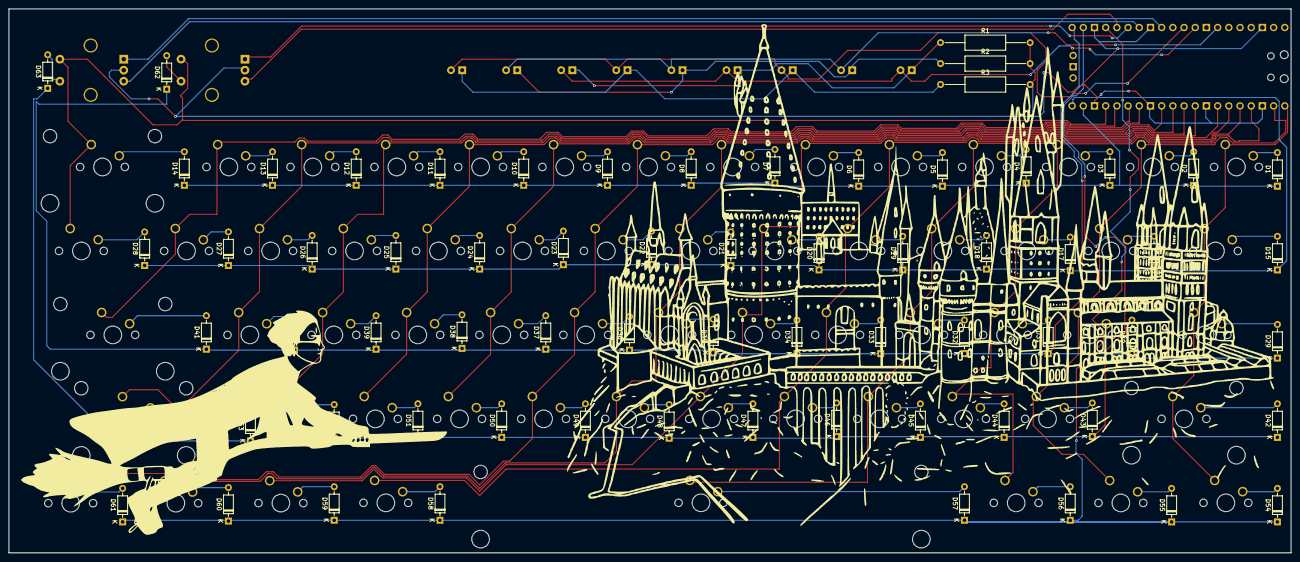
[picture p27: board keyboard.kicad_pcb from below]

Board: 2 copper layers, 290.9 x 123.4 mm, 139 parts (66 on the bottom side), 93 nets.

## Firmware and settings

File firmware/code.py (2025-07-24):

# Daamin's keyboard-v2 firmware
# Rev 1.3
# Copyright 2024
# Licensed under zlib license

import board
import busio
import digitalio
from kmk.kmk_keyboard import KMKKeyboard
from kmk.keys import KC
from kmk.scanners import DiodeOrientation
from kmk.modules.encoder import EncoderHandler
from kmk.extensions.media_keys import MediaKeys
from kmk.modules.mouse_keys import MouseKeys
from kmk.modules.layers import Layers
from kmk.modules.macros import Macros

# Pin definitions
ROT1A = board.GP19
ROT1B = board.GP20
ROT2A = board.GP22
ROT2B = board.GP21
COL1 = board.GP0
COL2 = board.GP1
COL3 = board.GP2
COL4 = board.GP3
COL5 = board.GP4
COL6 = board.GP5
COL7 = board.GP6
COL8 = board.GP7
COL9 = board.GP8
COL10 = board.GP9
COL11 = board.GP10
COL12 = board.GP11
COL13 = board.GP12
COL14 = board.GP13
ROW1 = board.GP14
ROW2 = board.GP15
ROW3 = board.GP16
ROW4 = board.GP17
ROW5 = board.GP18

# Layer definitions
LAYER_BASE = 0
LAYER_ALT = 1

keyboard = KMKKeyboard()
encoder_handler = EncoderHandler()
encoder_handler2 = EncoderHandler()
macros = Macros()

keyboard.extensions.append(MediaKeys())
keyboard.extensions.append(MouseKeys())
keyboard.modules.append(Layers())
keyboard.modules.append(encoder_handler)
keyboard.modules.append(encoder_handler2)
keyboard.modules.append(macros)

# Encoders
encoder_handler.pins = ((ROT1A, ROT1B, None),)
encoder_handler.map = [
    ((KC.UP, KC.DOWN),),    # Layer 1: Up / Down Arrow
    ((KC.VOLD, KC.VOLU),),  # Layer 0: Volume Up / Down
]

encoder_handler2.pins = ((ROT2A, ROT2B, None),)
encoder_handler2.map = [
    ((KC.RIGHT, KC.LEFT),), # Layer 1: Left / Right Arrow
    ((KC.MFFD, KC.MRWD),),  # Layer 0: Media Rewind / Fast Forward
]


keyboard.col_pins = (COL1, COL2, COL3, COL4, COL5, COL6, COL7, COL8, COL9, COL10, COL11, COL12, COL13, COL14)
keyboard.row_pins = (ROW1, ROW2, ROW3, ROW4, ROW5)
keyboard.diode_orientation = DiodeOrientation.COL2ROW

numero_uno = KC.TO(LAYER_ALT)
numero_dos = KC.TO(LAYER_BASE)

# LED control pins
led1 = digitalio.DigitalInOut(board.GP26)
led1.direction = digitalio.Direction.OUTPUT
led2 = digitalio.DigitalInOut(board.GP27)
led2.direction = digitalio.Direction.OUTPUT
led3 = digitalio.DigitalInOut(board.GP28)
led3.direction = digitalio.Direction.OUTPUT


led1.value = False
led2.value = False
led3.value = False

# Keymaps
keyboard.keymap = [
    # Layer 0 - Base Layer
    [
        KC.ESC,  KC.N1,   KC.N2,   KC.N3,   KC.N4,   KC.N5,   KC.N6,   KC.N7,   KC.N8,   KC.N9,   KC.N0,   KC.MINS, KC.EQL,  KC.BSPC,
        KC.TAB,  KC.Q,    KC.W,    KC.E,    KC.R,    KC.T,    KC.Y,    KC.U,    KC.I,    KC.O,    KC.P,    KC.LBRC, KC.RBRC, KC.BSLS,
        KC.CAPS, KC.A,    KC.S,    KC.D,    KC.F,    KC.G,    KC.H,    KC.J,    KC.K,    KC.L,    KC.SCLN, KC.QUOT, KC.ENT,  KC.MUTE,
        KC.LSFT, KC.Z,    KC.X,    KC.C,    KC.V,    KC.B,    KC.N,    KC.M,    KC.COMM, KC.DOT,  KC.SLSH, KC.RSFT, KC.NO, KC.MEDIA_PLAY_PAUSE,
        KC.LCTL, KC.LALT, KC.LGUI, KC.SPC,  KC.LGUI, KC.RALT, KC.RCTL, numero_uno,   KC.NO,   KC.NO,   KC.NO,   KC.NO,   KC.NO,   KC.NO,
    ],
    # Layer 1 - Alternate Layer
    [
        KC.GRAVE,  KC.N1,   KC.N2,   KC.N3,   KC.N4,   KC.N5,   KC.N6,   KC.N7,   KC.N8,   KC.N9,   KC.N0,   KC.MINS, KC.EQL,  KC.BSPC,
        KC.TAB,    KC.Q,    KC.W,    KC.E,    KC.R,    KC.T,    KC.Y,    KC.U,    KC.I,    KC.O,    KC.P,    KC.LBRC, KC.RBRC, KC.BSLS,
        KC.CAPS,   KC.A,    KC.S,    KC.D,    KC.F,    KC.G,    KC.H,    KC.J,    KC.K,    KC.L,    KC.SCLN, KC.QUOT, KC.ENT,  KC.MUTE,
        KC.LSFT,   KC.Z,    KC.X,    KC.C,    KC.V,    KC.B,    KC.N,    KC.M,    KC.COMM, KC.DOT,  KC.UP,   KC.RSFT, KC.NO, KC.MEDIA_PLAY_PAUSE,
        KC.LCTL,   KC.LALT, KC.LGUI, KC.SPC,  KC.LEFT, KC.DOWN, KC.RIGHT, numero_dos,   KC.NO,   KC.NO,   KC.NO,   KC.NO,   KC.NO,   KC.NO,
    ],
]

if __name__ == '__main__':
    keyboard.go()

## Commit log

2025-06-05 journaled: day-1
    [keyboard.kicad_pcb, keyboard.kicad_sch]
2025-06-08 add PCB
    [designators.csv, keyboard.kicad_pcb, keyboard.kicad_sch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]
2025-06-09 journal: day-3
    [keyboard.kicad_pcb]
2025-06-10 added final case: cad
    [acrylic-sheet-lid.step, acrylic-sheet-lid.stl, bottom.step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]
2025-06-10 Added PCB
    [keyboard.kicad_pcb, keyboard.kicad_sch]
2025-06-11 added readme and bom
    [bom.csv, designators.csv, keyboard.kicad_sch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]
2025-06-11 added bom.csv
    [acrylic-sheet-lid.step, acrylic-sheet-lid.stl, bom.csv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]
2025-06-11 updated bom
    [bom.csv]
2025-06-12 added RE and LED firmware
2025-06-16 make case 5° inclined
    [bom.csv, bottom.step, bottom.stl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]
2025-06-18 updated bom to include 3rd party printing
    [bom.csv]
